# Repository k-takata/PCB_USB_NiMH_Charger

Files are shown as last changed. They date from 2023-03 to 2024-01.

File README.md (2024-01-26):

# USB NiMH ゆっくり充電器 (USB NiMH Slow Charger)

## 概要

[秋月電子](https://akizukidenshi.com/)の[いたわりNiCd充電器 キット](https://akizukidenshi.com/img/contents/kairo/%E3%83%87%E3%83%BC%E3%82%BF/%E5%85%85%E9%9B%BB%E5%99%A8%E9%96%A2%E4%BF%82/H001%E3%81%84%E3%81%9F%E3%82%8F%E3%82%8ANiCd_.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)を元に、USBを電源とし、ニッケル水素電池を1本単位で2本まで充電できるようにした充電器です。

※単3と単4をそれぞれ2本ずつの計4本充電できるバージョンは[別ブランチ](https://github.com/k-takata/PCB_USB_NiMH_Charger/tree/batt-4)で準備しています。

## 使用したソフトウェア

KiCad 7.0

## 回路図

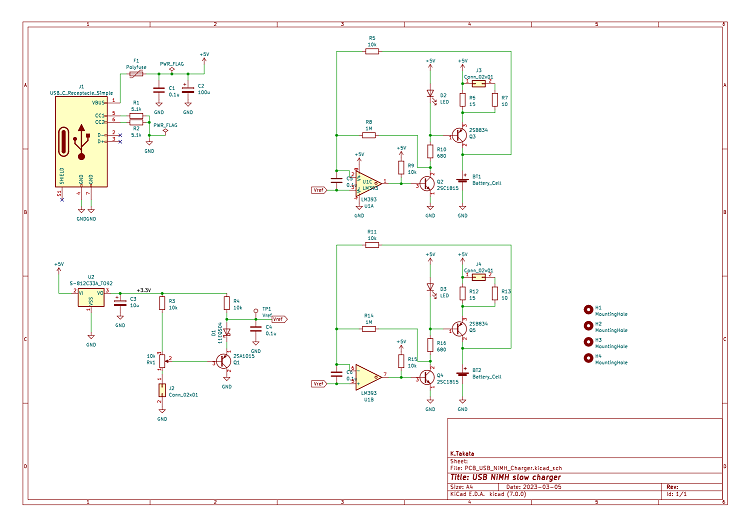
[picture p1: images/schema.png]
schema


## 基板パターン図

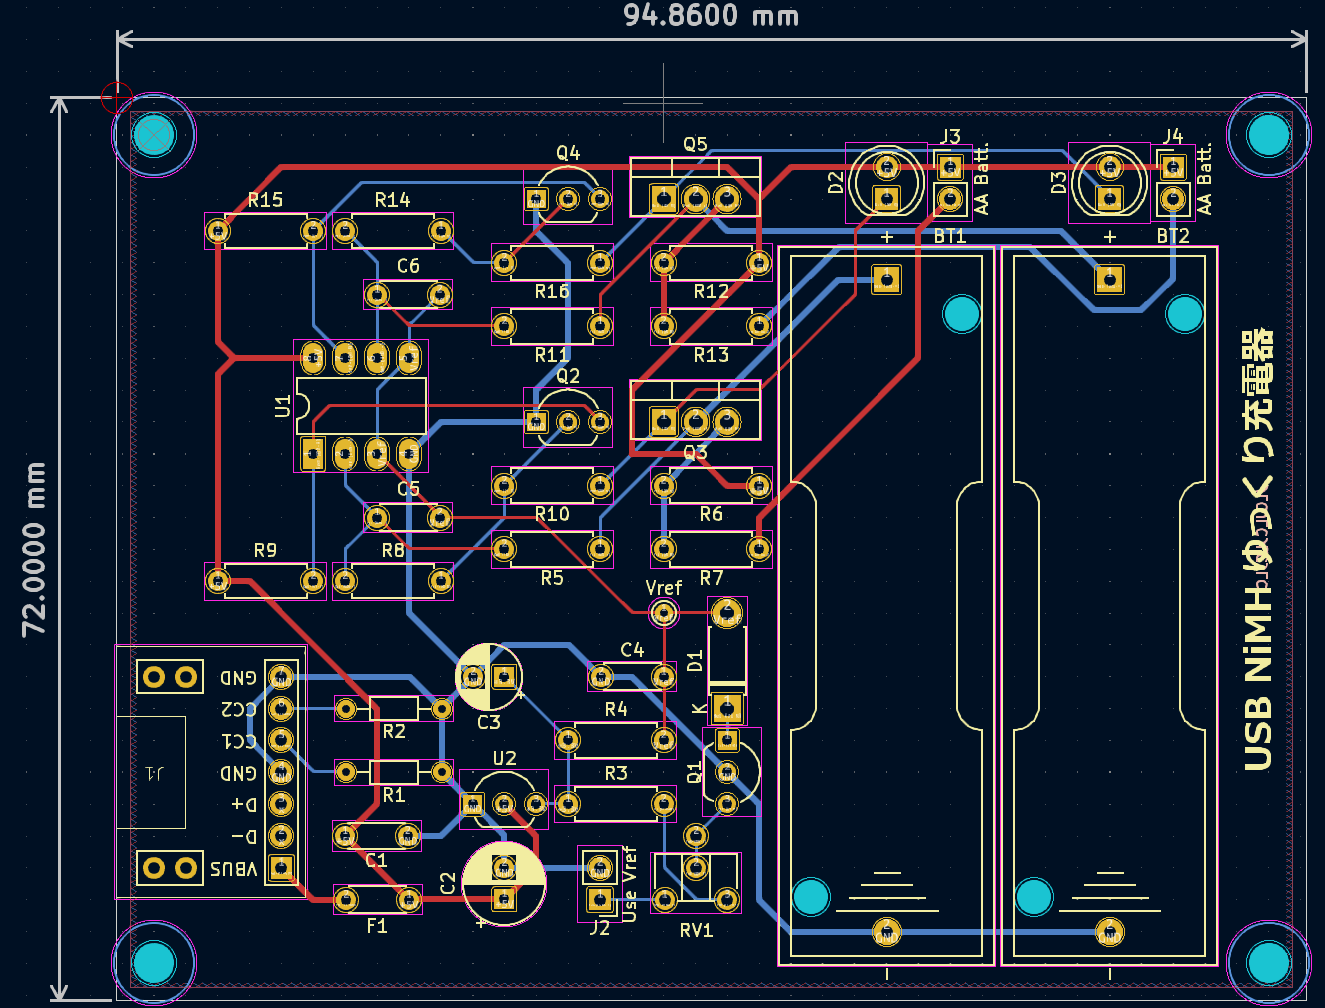
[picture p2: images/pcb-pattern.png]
PCB pattern


## 部品表

| Reference |個数|値 | 説明 |
|---|----|---|---|
|BT1, BT2 | 2| |[単3電池ボックス](https://akizukidenshi.com/catalog/g/g100308/)|
|C1, C4, C5, C6 | 4|0.1μF|積層セラミックコンデンサー|
|C2 | 1|220μF|電解コンデンサー φ6.3[^1] (100 ~ 470μF)|
|C3 | 1| 10μF|電解コンデンサー|
|D1 | 1|[11EQS04](https://akizukidenshi.com/catalog/g/g111363/)|ショットキーバリアダイオード|
|D2, D3 | 2| |赤色LED|
|F1 | 1|  1.1A|[ポリヒューズ](https://akizukidenshi.com/catalog/g/g100507/)|
|J1 | 1| |[USB Type-C コネクター](https://akizukidenshi.com/catalog/g/g113080/)、[同等品](https://akizukidenshi.com/catalog/g/g115426/)でも可|
|J2 | 1| |ピンヘッダー 1x2、強制充電用|
|J3, J4 | 2| |ピンヘッダー 1x2、単3/単4切り替え用|
|Q1 | 1|2SA1015||
|Q2, Q4 | 2|2SC1815||
|Q3, Q5 | 2|[2SB834](https://akizukidenshi.com/catalog/g/g108747/)|他の代替候補としては[2SA1441](https://akizukidenshi.com/catalog/g/g116790/)や[TTA008B](https://akizukidenshi.com/catalog/g/g109938/)、[2SB1185](https://akizukidenshi.com/catalog/g/g110994/) (h<sub>FE</sub> class E)などがある。（TTA008Bは2SB834などとはピン配置が異なるので裏返して取り付ける。）|
|R1, R2 | 2|5.1kΩ|緑茶赤金、小型|
|R3 | 1| 10kΩ|茶黒橙金、半固定抵抗RV1と同じ値|
|R4, R5, R9, R11, R15 | 5| 10kΩ|茶黒橙金|
|R6, R12 | 2|  15Ω|茶緑黒金、1/2W 小型|
|R7, R13 | 2|  10Ω|茶黒黒金、1/2W 小型|
|R8, R14 | 2|  1MΩ|茶黒緑金|
|R10, R16 | 2| 680Ω|青灰茶金|
|RV1 | 1| 10kΩ|抵抗R3と同じ値、[GF063P](https://akizukidenshi.com/catalog/g/g114905/)|
|U1 | 1|[LM393](https://akizukidenshi.com/catalog/g/g116987/)|2回路入りコンパレーター|
|U2 | 1|[S-812C33](https://akizukidenshi.com/catalog/g/g103289/)|低損失CMOS三端子レギュレーター 3.3V 50mA|

[^1]: このサイズならば、まっすぐ足が奥まで挿せる。

## いたわりNiCd充電器からの変更点

* 電源をACアダプターからUSB Type-Cに変更。
  - USB PD機器からも確実に電源を得られるようにするため、CC1, CC2には5.1kΩを接続。
  - 安全のため、ポリヒューズを使用。(1.1Aを使用したが0.5A程度でも十分かもしれない。)
* 充電を2本単位から1本単位に変更。
  - 基準電圧を5.0Vから3.3Vに変更。(U2をS-81350からS-812C33に変更。)
  - 温度補償用のダイオード1S2076A 2本をショットキーバリアダイオード1本に変更。  
    NiMH電池の充電終了時電圧には1本当たり約-3mV/Kの温度係数があります。PN接合には-2mV/Kの温度係数があることから、元の回路ではこれを3直列とし、2本分の-6mV/Kの補正を行っていました。ショットキーバリアダイオードの正確な温度係数は調べられませんでしたが、PN接合の温度係数より小さいよう(-1.0 ~ -1.5mV/K程度?)ですので、これをもって1本分の補正としています。
* 秋月電子の[B基板](https://akizukidenshi.com/catalog/r/rboard10)に実装できるよう、充電本数は2本に変更。
  - 充電回路は2セットになるため、コンパレーターを[LM339](https://akizukidenshi.com/catalog/g/g100436/)からLM393に変更。
* 充電電流を単3と単4用に切り替えられるようにJ3, J4を用意。
  - J3を開放すると電流設定抵抗はR6の15Ωとなり、BT1の充電電流は単4用の約70mA (= 1.05V / 15Ω)となります。(単4用変換アダプターなどを使用することを想定。)
  - J3を接続すると電流設定抵抗はR6とR7の合成で6Ωとなり、BT1の充電電流は単3用の約175mA (= 1.05V / 6Ω)となります。(2000mAhの場合は0.09C程度になるので充電時間は17時間程度が目安です。)
  - BT2については同様にJ4で設定できます。
* 強制充電用にJ2を用意。
  - 通常充電モード: 通常、J2は接続して使います。充電終止電圧の監視が行われます。
  - 強制充電モード: J2を開放すると、Vrefは3.3Vに設定され、充電終止電圧の監視が行われません。  
    新品のNiMH電池の内部抵抗は0.1Ω程度のようですが、寿命が近づいてくると徐々に内部抵抗が大きくなります。例えば内部抵抗が10Ωにもなると、70mAの充電電流を流すと端子電圧が0.7Vも上昇するため、正常に充電電圧の監視を行うことはできません。こうなってしまうと通常の充電器では充電することができません。そのような場合でも強制充電モードを使えば充電が可能です。ただし、充電電圧の監視がなくなってしまいますので、10～15時間程度で電池を外すようにしてください。
* 2SB948が入手できなかったので、簡単に入手できた2SB834に変更。
* RV1の回転方向を逆にし、右に回すほどVrefが高くなるように変更。

## 調整

J2を接続し、RV1を右に回しきって、700mAhの単4なら15時間程度、2000mAhの単3なら17時間程度充電します。この際、J3, J4は電池に合わせて設定しておいてください。電池を外して20分程度置いてから、再度電池を入れます。RV1を回して、LEDが点滅する位置に合わせて終了です。Vrefの電圧は1.40~1.45V程度になっているのが想定です。

## 完成品

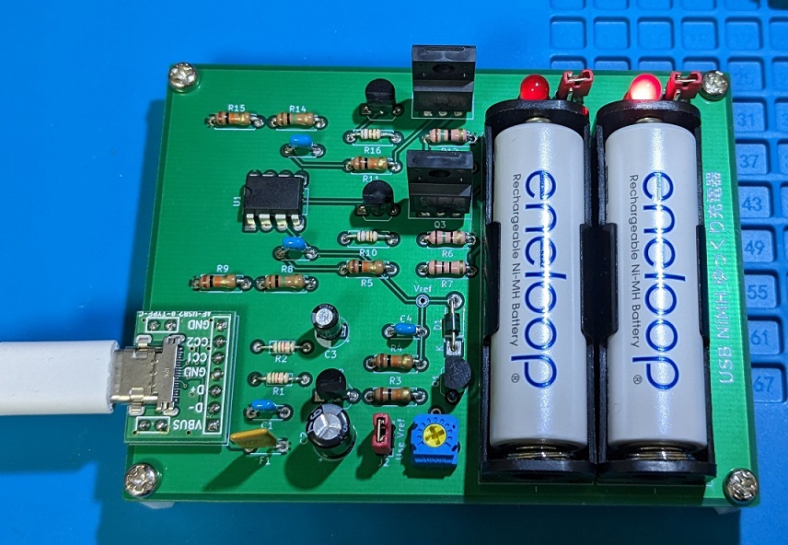
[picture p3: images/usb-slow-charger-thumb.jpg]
完成品


## License

CC0

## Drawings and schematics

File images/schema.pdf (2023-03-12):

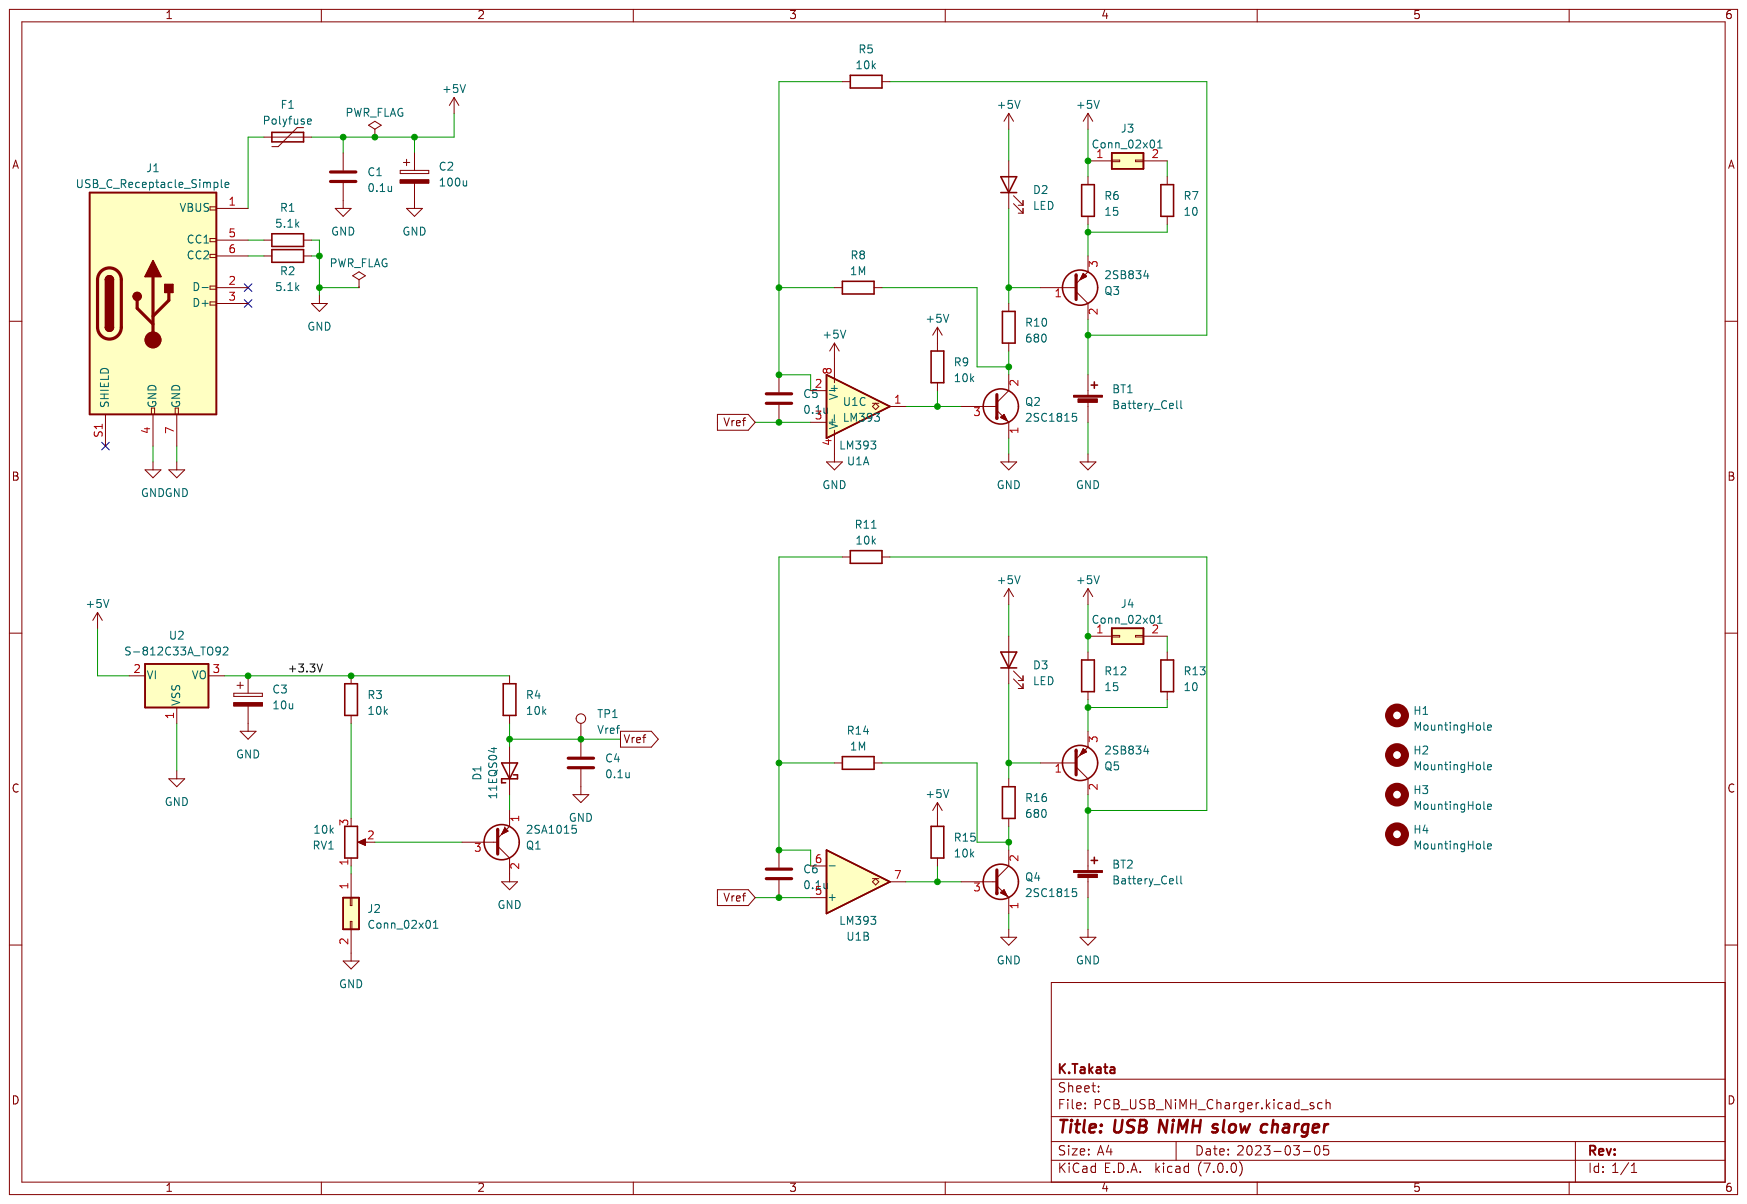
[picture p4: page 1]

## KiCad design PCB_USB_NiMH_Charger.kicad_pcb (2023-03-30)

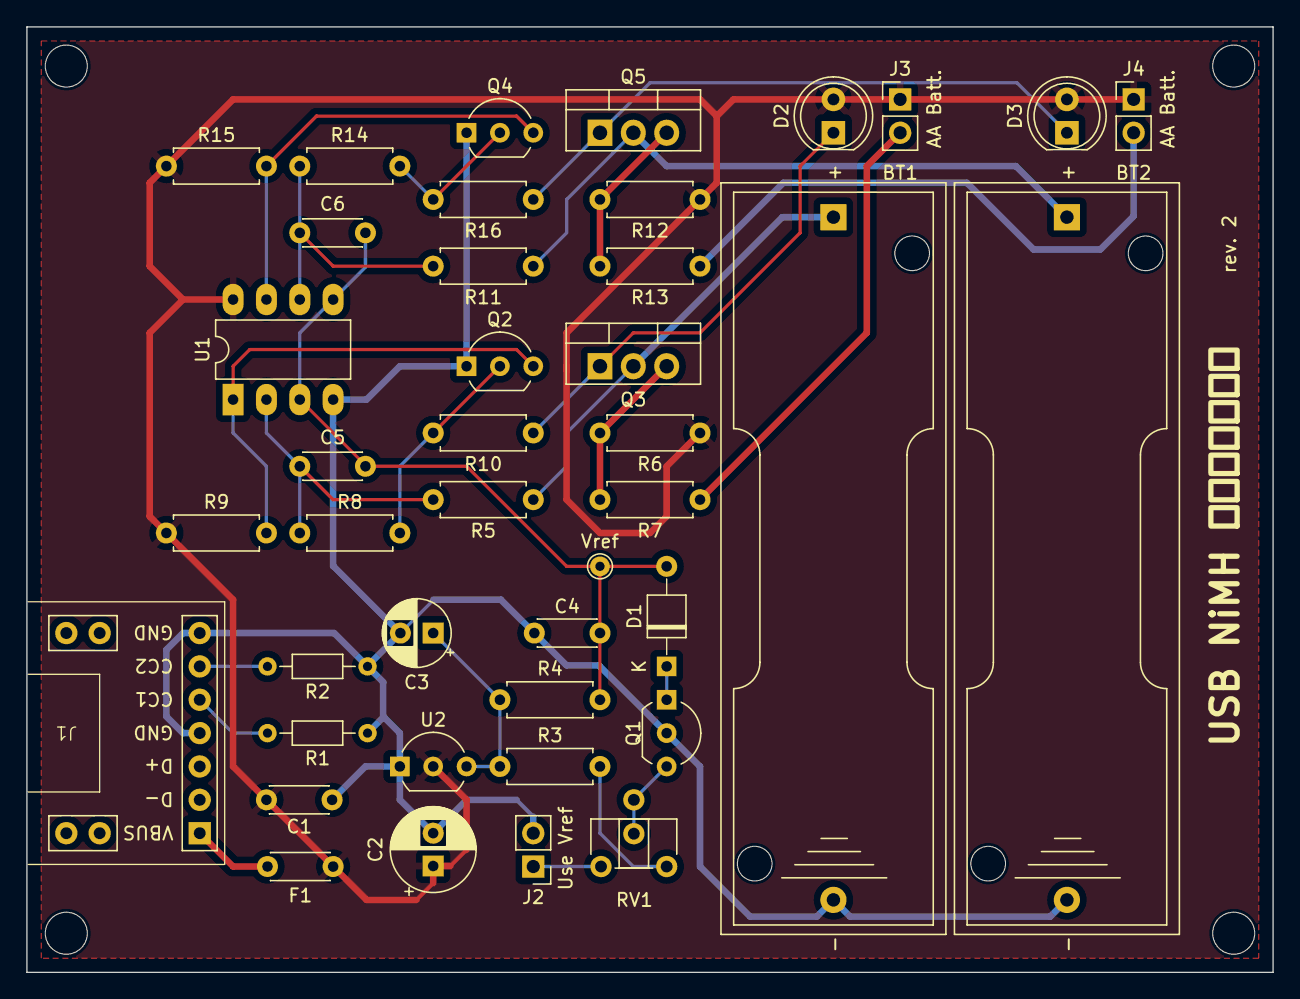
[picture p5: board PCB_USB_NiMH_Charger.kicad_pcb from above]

Board: 2 copper layers, 94.9 x 72.0 mm, 45 parts (0 on the bottom side), 25 nets.

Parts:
BT1, BT2: Battery_Cell; BatteryHolder_Keystone_2460_1xAA
C1, C4, C5, C6: 0.1u; C_Disc_D4.3mm_W1.9mm_P5.00mm
C2: 100u; CP_Radial_D6.3mm_P2.50mm
C3: 10u; CP_Radial_D5.0mm_P2.50mm
D1: 11EQS04; D_DO-41S_SOD81_P7.62mm_Horizontal
D2, D3: LED; LED_D5.0mm
F1: Polyfuse; C_Disc_D4.3mm_W1.9mm_P5.00mm
H1, H2, H3, H4: MountingHole; MountingHole_3.2mm_M3
J1: USB_C_Receptacle_Simple; Connector_USB_C_simple
J2, J3, J4: Conn_02x01; PinHeader_1x02_P2.54mm_Vertical
Q1: 2SA1015; TO-92_Inline_Wide
Q2, Q4: 2SC1815; TO-92_Inline_Wide
Q3, Q5: 2SB834; TO-220-3_Vertical
R1, R2: 5.1k; R_Axial_DIN0204_L3.6mm_D1.6mm_P7.62mm_Horizontal
R3, R4, R5, R9, R11, R15: 10k; R_Axial_DIN0207_L6.3mm_D2.5mm_P7.62mm_Horizontal
R6, R12: 15; R_Axial_DIN0207_L6.3mm_D2.5mm_P7.62mm_Horizontal
R7, R13: 10; R_Axial_DIN0207_L6.3mm_D2.5mm_P7.62mm_Horizontal
R8, R14: 1M; R_Axial_DIN0207_L6.3mm_D2.5mm_P7.62mm_Horizontal
R10, R16: 680; R_Axial_DIN0207_L6.3mm_D2.5mm_P7.62mm_Horizontal
RV1: 10k; Potentiometer_ACP_CA6-H2-3,5_Horizontal
TP1: Vref; TestPoint_THTPad_D1.5mm_Drill0.7mm
U1: LM393; DIP-8_W7.62mm_LongPads
U2: S-812C33A_TO92; TO-92_Inline_Wide

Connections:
+5V: C1.1, C2.1, D2.2 (A), D3.2 (A), F1.1, J3.1, J4.1, R6.1, R9.1, R12.1, R15.1, U1.8 (V+), U2.2 (VI)
/+3.3V: C3.1, R3.1, R4.1, U2.3 (VO)
/VBUS: F1.2, J1.1 (VBUS)
GND: BT1.2 (-), BT2.2 (-), C1.2, C2.2, C3.2, C4.2, J1.4 (GND), J1.7 (GND), J2.2, Q1.2 (C), Q2.1 (E), Q4.1 (E), R1.1, R2.1, U1.4 (V-), U2.1 (VSS)
unnamed: BT1.1 (+), Q3.2 (C), R5.1
unnamed: BT2.1 (+), Q5.2 (C), R11.1
unnamed: D1.1 (K), Q1.1 (E)
unnamed: D2.1 (K), Q3.1 (B), R10.1
unnamed: D3.1 (K), Q5.1 (B), R16.1
unnamed: J1.5 (CC1), R1.2
unnamed: J1.6 (CC2), R2.2
unnamed: J2.1, RV1.1
unnamed: J3.2, R7.1
unnamed: J4.2, R13.1
unnamed: Q1.3 (B), RV1.2
unnamed: Q2.3 (B), R9.2, U1.1
unnamed: Q2.2 (C), R8.1, R10.2
unnamed: Q3.3 (E), R6.2, R7.2
unnamed: Q4.3 (B), R15.2, U1.7
unnamed: Q4.2 (C), R14.1, R16.2
unnamed: Q5.3 (E), R12.2, R13.2
unnamed: R3.2, RV1.3
unnamed: C5.1, R5.2, R8.2, U1.2 (-)
unnamed: C6.1, R11.2, R14.2, U1.6 (-)
Vref: C4.1, C5.2, C6.2, D1.2 (A), R4.2, TP1.1, U1.3 (+), U1.5 (+)

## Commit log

2023-03-11 Add schematics and pcb
    [PCB_USB_NiMH_Charger.kicad_pcb, PCB_USB_NiMH_Charger.kicad_sch]
2023-03-18 doc: 完成品の写真を追加
2023-03-18 doc: 抵抗のカラーコードを追加
2023-03-20 doc: C2のサイズを変更
2023-03-21 初版の知見を反映した細かい調整
    * VBUSをラベル付け。
    * USBコネクタのパッドの穴のサイズを0.9mmに縮小。
    * ネットクラスに "Power" を追加。
    * D1用にDO-41Sのフットプリントを追加。
    * R8, R9, R14, R15 の配置を調整。
    * 配線を調整。
    [PCB_USB_NiMH_Charger.kicad_pcb, PCB_USB_NiMH_Charger.kicad_sch]
2023-03-21 パッドとベタの接続形状を調整
    [PCB_USB_NiMH_Charger.kicad_pcb]
2023-03-21 Add rev. 2 silk
    * rev. 2 のシルクを追加。
    * 配線の表裏を調整。
    [PCB_USB_NiMH_Charger.kicad_pcb]
2023-03-22 Update title to rev. 2
    [PCB_USB_NiMH_Charger.kicad_sch]
2023-03-23 doc: Update README.md
    J3, J4の設定について少し追記。
2023-03-27 doc: Update README
    4本充電バージョンのリンクを記載
2023-03-29 Update revision
    [PCB_USB_NiMH_Charger.kicad_pcb, PCB_USB_NiMH_Charger.kicad_sch]
2023-03-30 基板外形を調整
    [PCB_USB_NiMH_Charger.kicad_pcb]
2023-03-30 Update drill origin
    [PCB_USB_NiMH_Charger.kicad_pcb]
2023-03-30 Adjust schema layout
    [PCB_USB_NiMH_Charger.kicad_sch]
2024-01-26 Update links
    秋月電子のサイトリニューアルに対応。
